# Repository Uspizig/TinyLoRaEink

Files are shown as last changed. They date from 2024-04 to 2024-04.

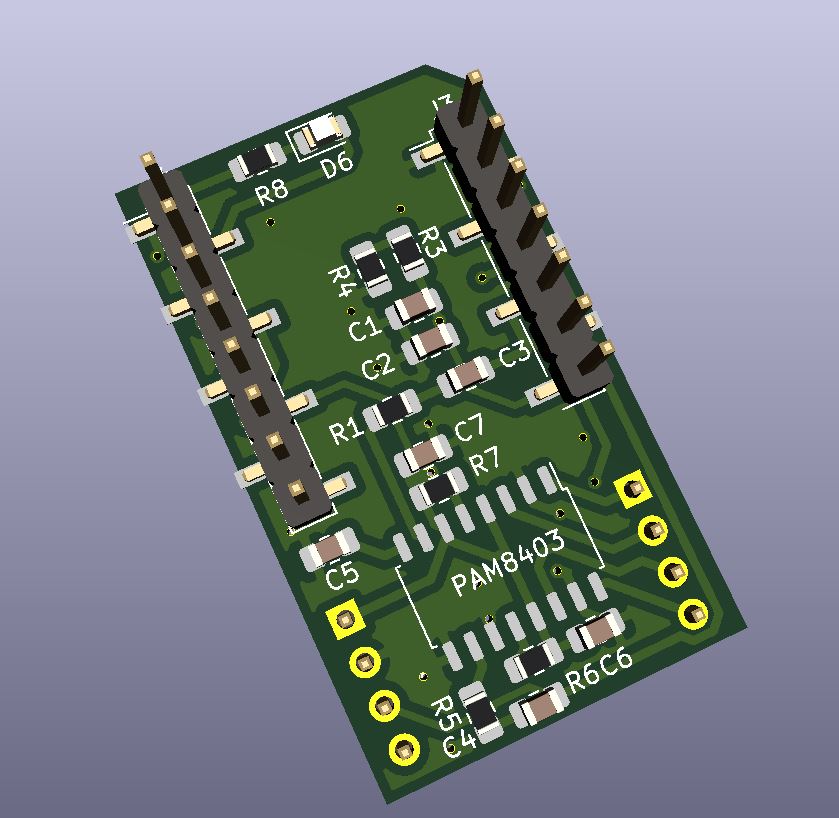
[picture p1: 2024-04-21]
1.JPG

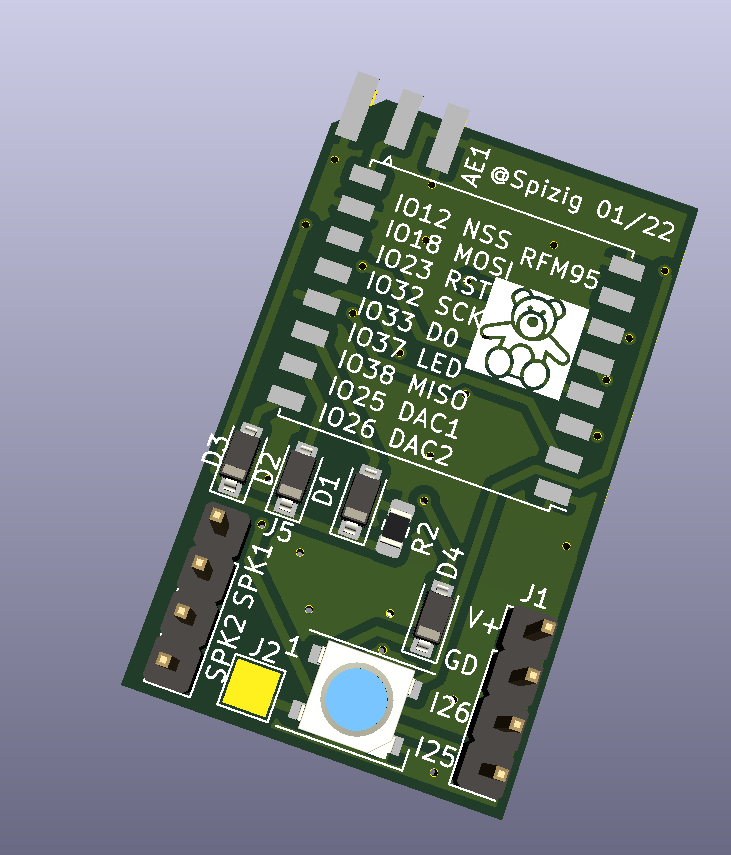
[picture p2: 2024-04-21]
front.PNG

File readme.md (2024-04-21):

This is a Lora Shield for the Lilygo Mini Epaper Core 1.05". 
With this shield you may enable LoRa Communication, Chirpstack or stupid Helium on a Lilygo Mini Epaper Core ESP32 (Not the S3 for now)

In the Attached folder you may find

Schematic(PDF)
Gerber Files(Zip File)
Demofiles for reading out a Bresser Weather Station
Changes in the SW for https://github.com/mcci-catena/arduino-lmic
You may change the following lines in the SW of Arduino-LMIC: To do this Change in the folder Arduino\libraries\arduino-lmic-master\src\hal the File hal.cpp the function "static void hal_spi_init to": static void hal_spi_init () { //SPI.begin();//Comment Uspizig Original und WEMOS D1 //SPI.begin(lmic_pins.sck, lmic_pins.miso, lmic_pins.mosi, lmic_pins_cs); //sck, miso, mosi, cs SPI.begin(23, 22, 19, 33);//Comment Uspizig M5Matrix Lora Modul }

Part List/BOM: SMD-Stiftleiste: SMD RM2.54 z.B. https://www.conrad.de/de/p/fischer-elektronik-stiftleiste-standard-anzahl-reihen-1-polzahl-je-reihe-20-sl-10-smd-062-20-z-1-st-739077.html

MBR0530-SOD123: D1, D2, D3 -> Anode towards RFM95 DIO0, DIO1, DIO2 Kathode direction to D4, R1 https://www.conrad.de/de/p/mbr-0530-t1g-diode-schottky-smd-0-5a-30v-sod123-inhalt-50-stueck-800112525.html

0805 Resistor 4k7 or 10k or 1k PullDown Resistor-> R2 Choose whatever you have availible in Kohm.

RFM95 Lora TTN Module: https://www.conrad.de/de/p/rfm95w-868-s2-lora-module-868mhz-20-123dbm-300kbps-1-8-3-7v-800167586.html

Wire as a Antenna L = 3 x 10^8 m/s : 868 MHz : 4 = 86,3 mm

Optional: C1 100nF 0805 C2 1µF 0805

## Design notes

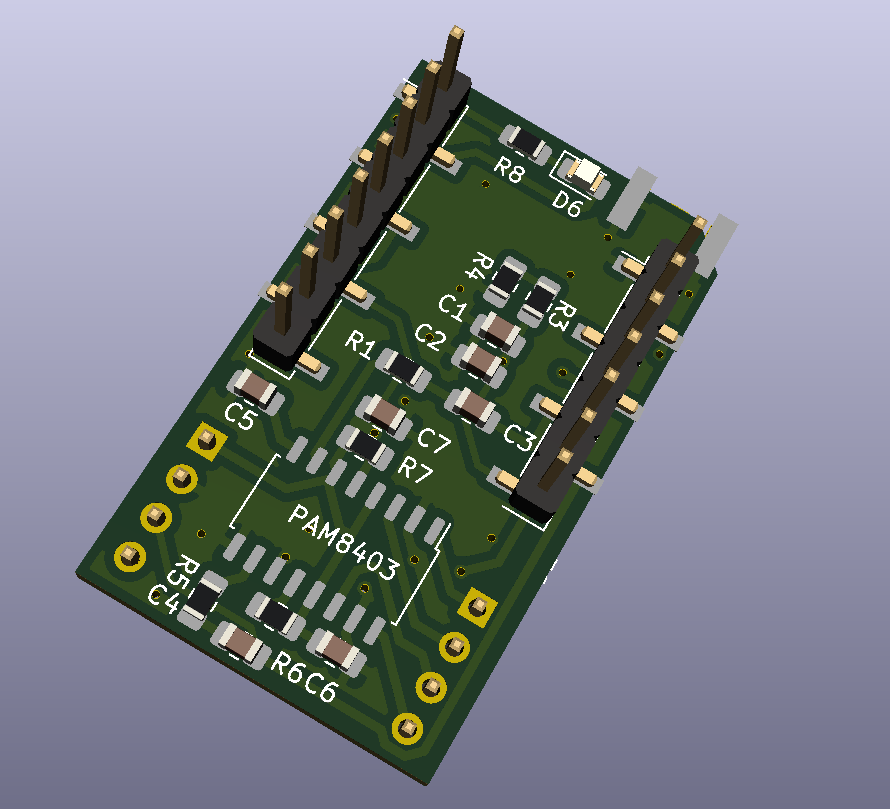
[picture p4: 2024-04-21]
back.PNG

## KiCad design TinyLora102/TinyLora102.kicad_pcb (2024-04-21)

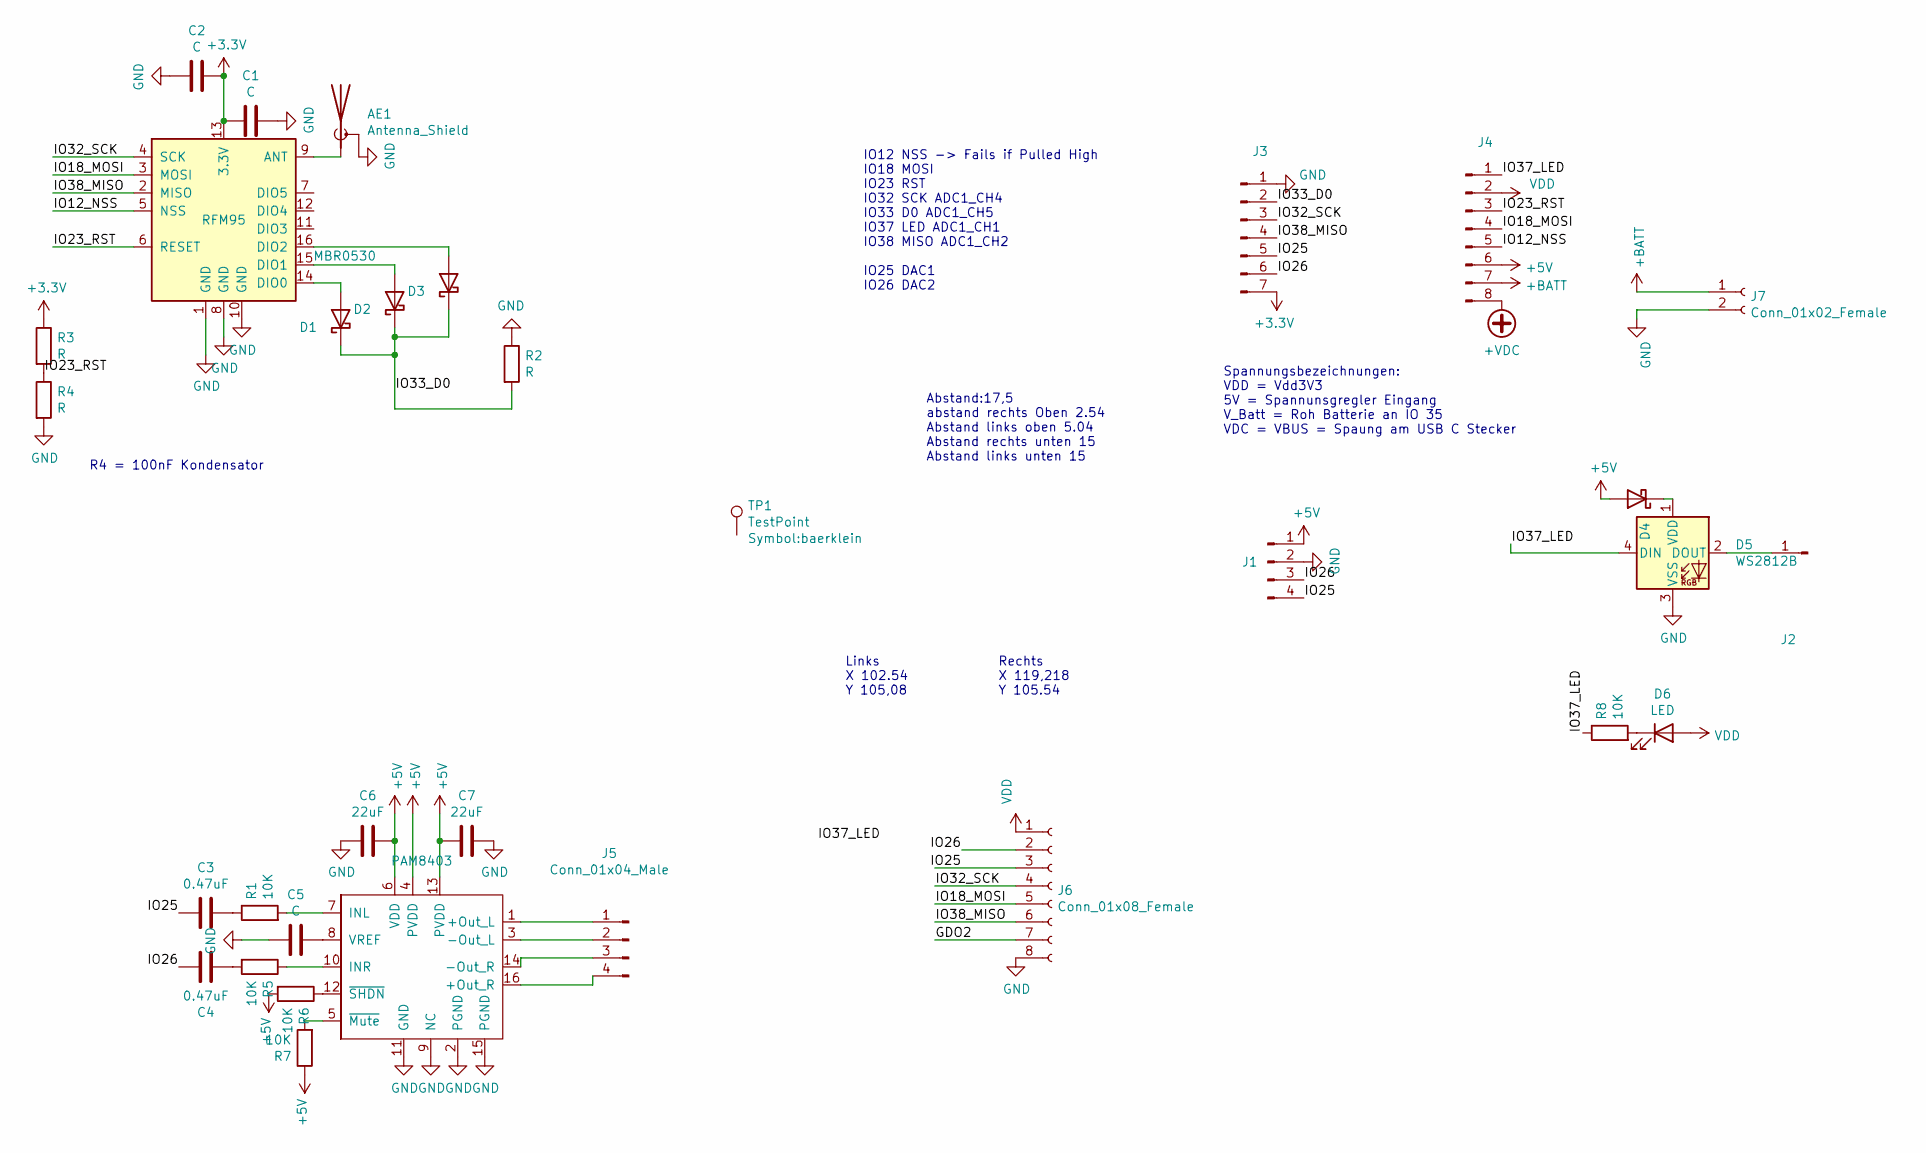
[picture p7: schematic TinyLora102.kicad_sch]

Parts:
AE1: Antenna_Shield; SMA_Samtec_SMA-J-P-H-ST-EM1_EdgeMount
C1, C2, C5: C; C_0805_2012Metric_Pad1.15x1.40mm_HandSolder
C3, C4: 0.47uF; C_0805_2012Metric_Pad1.15x1.40mm_HandSolder
C6, C7: 22uF; C_0805_2012Metric_Pad1.15x1.40mm_HandSolder
D1, D2, D3, D4: MBR0530; D_SOD-123
D5: WS2812B; LED_WS2812B_PLCC4_5.0x5.0mm_P3.2mm
D6: LED; LED_0805_2012Metric_Pad1.15x1.40mm_HandSolder
J1, J5: Conn_01x04_Male; PinHeader_1x04_P2.54mm_Vertical
J2: Conn_01x01_Male; TestPoint_Pad_2.5x2.5mm
J3: Conn_01x07_Male; PinHeader_1x07_P2.54mm_Vertical_SMD_Pin1Left
J4: Conn_01x08_Male; PinHeader_1x08_P2.54mm_Vertical_SMD_Pin1Left
J6: Conn_01x08_Female; PinHeader_1x08_P1.27mm_Vertical
J7: Conn_01x02_Female; JST_GH_SM02B-GHS-TB_1x02-1MP_P1.25mm_Horizontal
PAM8403: PAM8403; SOP-16_4.55x10.3mm_P1.27mm
R1, R5, R6, R7, R8: 10K; R_0805_2012Metric_Pad1.15x1.40mm_HandSolder
R2, R3, R4: R; R_0805_2012Metric_Pad1.15x1.40mm_HandSolder
RFM95: RFM95W-868S2; HOPERF_RFM9XW_SMD_3D
TP1: TestPoint; baerklein

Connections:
+3V3: C1.2, C2.1, J3.7, R3.1, RFM95.13 (3.3V)
+5V: C6.1, C7.2, D4.2 (A), J1.1, J4.6, PAM8403.4 (PVDD), PAM8403.6 (VDD), PAM8403.13 (PVDD), R6.2, R7.1
+BATT: J4.7, J7.1; also elsewhere on the board
+VDC: J4.8
/GDO2: J6.7
/IO12_NSS: J4.5, RFM95.5 (NSS)
/IO18_MOSI: J4.4, J6.5, RFM95.3 (MOSI)
/IO23_RST: J4.3, R3.2, R4.1, RFM95.6 (RESET)
/IO25: C3.2, J1.4, J3.5, J6.3
/IO26: C4.1, J1.3, J3.6, J6.2
/IO32_SCK: J3.3, J6.4, RFM95.4 (SCK)
/IO33_D0: D1.1 (K), D2.1 (K), D3.1 (K), J3.2, R2.2
/IO37_LED: D5.4 (DIN), J4.1, R8.1
/IO38_MISO: J3.4, J6.6, RFM95.2 (MISO)
GND: AE1.2 (Shield), C1.1, C2.2, C5.2, C6.2, C7.1, D5.3 (VSS), J1.2, J3.1, J6.8, J7.2, PAM8403.2 (PGND), PAM8403.9 (NC), PAM8403.11 (GND), PAM8403.15 (PGND), R2.1, R4.2, RFM95.1 (GND), RFM95.8 (GND), RFM95.10 (GND); also elsewhere on the board
unnamed: AE1.1 (A), RFM95.9 (ANT)
unnamed: C3.1, R1.1
unnamed: C4.2, R5.2
unnamed: C5.1, PAM8403.8 (VREF)
unnamed: D1.2 (A), RFM95.14 (DIO0)
unnamed: D2.2 (A), RFM95.15 (DIO1)
unnamed: D3.2 (A), RFM95.16 (DIO2)
unnamed: D4.1 (K), D5.1 (VDD)
unnamed: D5.2 (DOUT), J2.1
unnamed: D6.1 (K), R8.2
unnamed: J5.1, PAM8403.1 (+Out_L)
unnamed: J5.2, PAM8403.3 (-Out_L)
unnamed: J5.3, PAM8403.14 (-Out_R)
unnamed: J5.4, PAM8403.16 (+Out_R)
unnamed: PAM8403.5 (~Mute), R7.2
unnamed: PAM8403.7 (INL), R1.2
unnamed: PAM8403.10 (INR), R5.1
unnamed: PAM8403.12 (~SHDN), R6.1
VDD: D6.2 (A), J4.2, J6.1

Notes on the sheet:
Spannungsbezeichnungen: VDD = Vdd3V3 5V = Spannunsgregler Eingang V_Batt = Roh Batterie an IO 35 VDC = VBUS = Spaung am USB C Stecker
Abstand:17,5 abstand rechts Oben 2.54 Abstand links oben 5.04 Abstand rechts unten 15 Abstand links unten 15
Rechts X 119,218 Y 105.54
Links X 102.54 Y 105,08
IO12 NSS -> Fails if Pulled High IO18 MOSI IO23 RST IO32 SCK ADC1_CH4 IO33 D0 ADC1_CH5 IO37 LED ADC1_CH1 IO38 MISO ADC1_CH2 IO25 DAC1 IO26 DAC2
R4 = 100nF Kondensator

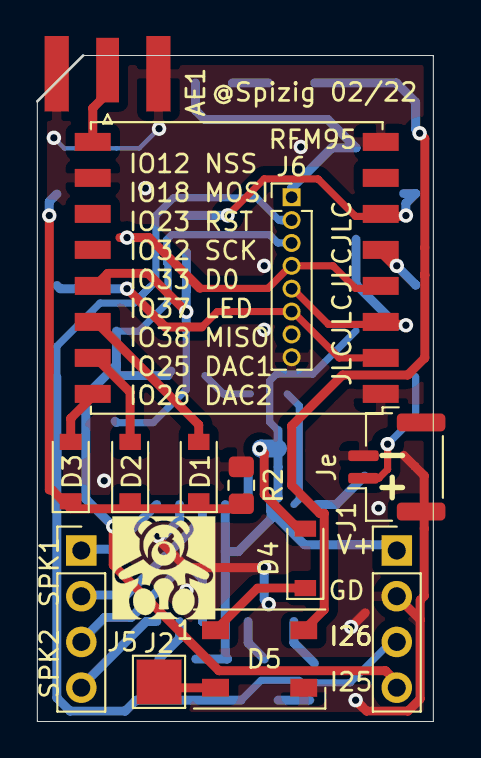
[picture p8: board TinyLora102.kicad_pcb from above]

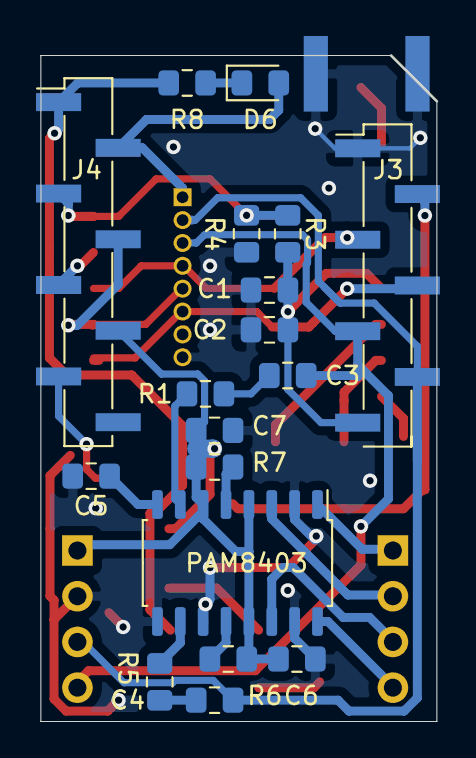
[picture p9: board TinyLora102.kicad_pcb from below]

Board: 2 copper layers, 22.0 x 37.0 mm, 32 parts (18 on the bottom side), 32 nets.

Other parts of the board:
Je: Conn_01x02_Female; JST_GH_SM02B-GHS-TB_1x02-1MP_P1.25mm_Horizontal

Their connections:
+BATT: Je.1; also elsewhere on the board
GND: Je.2; also elsewhere on the board

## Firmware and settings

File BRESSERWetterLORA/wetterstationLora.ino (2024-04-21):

//Features:
// - V3 Stack TTN Kompatibel, Ardunio ESP32 Core V2.0 Tested
// - Macht OTAA Join einmal im Leben, dann nur noch ABP
// - Decodiert 
// Geraet 9 = Self Made Hardware
// Geraet10 = TTGO LORA32 T3 V1.6

//To make this sketch work:

//Download these libs
/*
Libs: 
https://www.partsnotincluded.com/fastled-rgbw-neopixels-sk6812/
https://github.com/FastLED/FastLED
https://github.com/matthias-bs/BresserWeatherSensorReceiver
https://github.com/mcci-catena/arduino-lmic

*/

//MANDATORY CHANGES to MAKE IT WORK
//Hal.cpp changes:
//in hal.cpp replaced spi.begin(); to spi.begin(14, 2, 15, 26); to match YOUR pinning (lmic_pins.sck, lmic_pins.miso, lmic_pins.mosi, lmic_pins.nss)
  //SPI.begin();
/*
static void hal_spi_init () {
    //SPI.begin();//Original Änderung in hal.cpp
  //SPI.begin(lmic_pins.sck, lmic_pins.miso, lmic_pins.mosi, lmic_pins.nss);
  SPI.begin(14, 2, 15, 26);//this should match your pinning.. i copied a demo hal.cpp in the github folder
}

//Weathersensor.cpp
//Replace in the lib SRC folder https://github.com/matthias-bs/BresserWeatherSensorReceiver the weathersensor.cpp file with mine
// add in your folder the WaetherSensor.cfg file.
*/




//for Debugging
//#define SingleChannelMode 1 //to check on own gateway Join Behaviour
#define LMIC_DEBUG_LEVEL 1

#define geraet11 //TTGO MINI EPAPER CORE 1.02" // WETTER 02 in Wildwetter

//const unsigned long UpdateInterval = (60L * 20L - 03) * 1000000L; // Update delay in microseconds
//#define uS_TO_S_FACTOR 1000000  /* Conversion factor for micro seconds to seconds */


//Battery Pin
#define BATTERY_PIN 35
#include "OTA.h"
#include "credentials.h" 

#include "lorapindef_and_features.h"  
#include <lmic.h>
#include <hal/hal.h>
#include <SPI.h>
#include <EEPROM.h>

#include <FastLED.h> //https://github.com/FastLED/FastLED
#include <LoraMessage.h> //https://github.com/thesolarnomad/lora-serialization/

// include the library
#ifdef CC1101_CONNECTED
  #include <RadioLib.h>
  // https://github.com/jgromes/RadioLib
  SPIClass spiCC1101(VSPI);//https://github.com/espressif/arduino-esp32/issues/1219
  CC1101 radio = new Module(CC_CS, CC_GD0, RADIOLIB_NC, CC_GD2, spiCC1101, SPISettings()); //https://github.com/jgromes/RadioLib/issues/168
  //CC1101 radio = new Module(CC_CS, CC_GD0, RADIOLIB_NC, CC_GD2);
  byte fullMessage[40];
  bool receivedFlag = false;
  bool enableInterrupt = true;
  
#endif

#ifdef RFM95_WEATHER_DECODER
    #include "WeatherSensorCfg.h"
    #include "WeatherSensor.h" //https://github.com/matthias-bs/BresserWeatherSensorReceiver
    WeatherSensor weatherSensor;
#endif


#ifdef SSD1306_DISPLAY
  #include <Adafruit_GFX.h>
  #include <Adafruit_SSD1306.h>
  #define SCREEN_WIDTH 128 // OLED display width, in pixels
  #define SCREEN_HEIGHT 64 // OLED display height, in pixels
  #define OLED_SDA 21
  #define OLED_SCL 22 
  Adafruit_SSD1306 display(SCREEN_WIDTH, SCREEN_HEIGHT, &Wire);
#endif

#ifdef EINKDISPLAY102TTGO
  #include <GxEPD2_BW.h>
  #include <GxEPD2_3C.h>
  #include <Fonts/FreeMonoBold9pt7b.h>

  #include <GxEPD2_BW.h>
  #include "GxEPD2_boards_added.h"
  GxEPD2_BW<GxEPD2_102, GxEPD2_102::HEIGHT> display(GxEPD2_102(/*CS=5*/ E_INK_PIN_SPI_CS, /*DC=*/ E_INK_PIN_SPI_DC, /*RST=*/ E_INK_PIN_SPI_RST, /*BUSY=*/ E_INK_PIN_SPI_BUSY)); // GxEPD2_102
  #define Large  5           // For icon drawing, needs to be odd number for best effect
  #define Small  3            // For icon drawing, needs to be odd number for best effect
  boolean LargeIcon = true, SmallIcon = false; //250x122 Pixel
  const uint16_t window_x = 0;
  const uint16_t window_y = 0;
  const uint16_t window_width = 128;
  const uint16_t window_height = 80;
#endif
//Led Einstellungen
  
  FASTLED_USING_NAMESPACE
  #define MAX_POWER_MILLIAMPS 500
  #ifdef WS2812_LEDS
    CRGB leds[ANZAHL_LEDS];
    CRGB leds2[OBEN_LEDS];
  #endif
  #ifdef SK6812_LEDS
    #include "FastLED_RGBW.h" //https://www.partsnotincluded.com/fastled-rgbw-neopixels-sk6812/
    CRGBW leds[ANZAHL_LEDS];
    CRGB *ledsRGB = (CRGB *) &leds[0];

    //Beleuchtung des Drehreglers
    CRGBW leds2[OBEN_LEDS];
    CRGB *ledsRGB2 = (CRGB *) &leds2[0];
  #endif  
  static uint8_t gHue = 0;

uint8_t hue, hue2 = 0;
boolean zielwert_erreicht =0;
uint8_t Aktuelle_LED=0;
uint8_t schleifenzaehler = 0;
int vorher_message =0;
int counter = 0;
int lastcounter=0;
int counter_last=0;
int setup_lora_sucesful_flag =0;



//Temperatur:
#include <Wire.h>
#ifdef BMP280_CONNECTED
  #include <Adafruit_BMP280.h>
  Adafruit_BMP280 bmp; // I2C
#endif

#ifdef BME280_CONNECTED
  #define SEALEVELPRESSURE_HPA (1013.25)
  #include <Adafruit_BME280.h>
  Adafruit_BME280 bme;
#endif

#ifdef CCS811_CONNECTED 
  #include <SparkFunCCS811.h> //Click here to get the library: http://librarymanager/All#SparkFun_CCS811
  CCS811 myCCS811(CCS811_ADRESS);
#endif



#ifdef geraet3
  #define sda 21 ///* I2C Pin Definition */
  #define scl 22 ///* I2C Pin Definition */
#else
  #define sda 21 ///* I2C Pin Definition */
  #define scl 22 ///* I2C Pin Definition */
#endif


#ifdef WIFISCAN_CONNECTED
  long lastMsg = 0;
  #define updaterateWIFI 3000
#endif


#ifdef CC1101_CONNECTED
  float temp_cc1101 =0;
  float humidity_cc1101 =0;
  int pressure_cc1101 =0;
  int rain_cc1101 =0;
  int wind_speed_cc1101 =0;
  int wind_speed_max_cc1101 =0;
  int wind_dir_cc1101 =0;
  int count_decoded_wind_messages =0;
#endif

#ifdef RFM95_WEATHER_DECODER
  float temp_cc1101 =0;
  float humidity_cc1101 =0;
  int pressure_cc1101 =0;
  int rain_cc1101 =0;
  int wind_speed_cc1101 =0;
  int wind_speed_max_cc1101 =0;
  int wind_dir_cc1101 =0;
  int count_decoded_wind_messages =0;
#endif

float temp = 23;
float pressure = 980;
float humidity = 50;
float ccs811_CO2 = 450;
float ccs811_TVOC = 2;
int battery = 50;
int port = 1;

typedef struct {
   int Temp;
   int Feuchte;
   int Temp_max;
   int Temp_min;
   int Condition_Code;
   int Muell_Code;
} payload_record_type;
  
payload_record_type vorhersage[1];





#include "esp_timer.h"
#include "Arduino.h"
#include "fb_gfx.h"
//#include "fd_forward.h"
//#include "fr_forward.h"
#include "soc/soc.h"           // Disable brownout problems
#include "soc/rtc_cntl_reg.h"  // Disable brownout problems
#include "driver/rtc_io.h"
#include "WiFi.h"
#include <WiFiClientSecure.h>
#include <ArduinoJson.h> 
#include "credentials.h"  
//char ssid[] = mySSID;     // your network SSID (name)
//char password[] = myPASSWORD; // your network key


WiFiClientSecure client;

/*Wifi Sort Test*/
#define WIFI_DELAY        500
#define MAX_SSID_LEN      32 /* Max SSID octets. */
char ssid2[MAX_SSID_LEN] = "";/* SSID that to be stored to connect. */
#define WIFI_DELAY        500/* Delay paramter for connection. */

typedef struct { /*Struct für einfache Speicherung der Daten*/
  
   byte mac0;
   byte mac1;
   byte mac2;
   byte mac3;
   byte mac4;
   byte mac5;
   String mac;
   int EmpfangsPegel;
   int Encrypted;
} Wifi_record_type;
Wifi_record_type Found_Wifi[5];




uint32_t start_time;
uint32_t next_time;
uint32_t previous_time;
uint32_t previous_full_update;

uint32_t total_seconds = 0;
uint32_t startup_seconds = 0;
uint32_t seconds, minutes, hours, days;

uint32_t join_total_seconds = 0;
uint32_t join_seconds, join_minutes, join_hours, join_days;

//Partial Update:
const uint32_t partial_update_period_s = 30;
//const uint32_t full_update_period_s = 60 * 60 * 60;//alle 2.5 Tage
const uint32_t full_update_period_s = 60 * 60;//(jede Stunde)
//const uint32_t full_update_period_s = 60;(jede Minute)
/*EINK Teile ENDE*/

//Variables for ABP after OTAA Join
u1_t NWKSKEY[16] ;                               // LoRaWAN NwkSKey, network session key.
u1_t APPSKEY[16] ;                               // LoRaWAN AppSKey, application session key.
u4_t DEVADDR ;



//RealTimeVariables which don't get erased during Sleep
  struct Daten_struct {//https://esp32.com/viewtopic.php?t=11984
    uint16_t Stack[15];
    uint8_t Counter_History;
  };
  RTC_DATA_ATTR uint32_t SAVED_dataValid ;                           // DATAVALID if valid data (joined)
  RTC_DATA_ATTR uint8_t  SAVED_devaddr[4] ;                          // Device address after join
  RTC_DATA_ATTR uint8_t  SAVED_nwkKey[16] ;                          // Network session key after join
  RTC_DATA_ATTR uint8_t  SAVED_artKey[16] ;                          // Aplication session key after join
  RTC_DATA_ATTR uint32_t SAVED_seqnoUp ;                             // Sequence number       
  bool OTAA = true ;   //startup with OTAA if No EEPROM was Saved before
  //History of Data
  RTC_DATA_ATTR  struct Daten_struct Druck_Werte;                 
  RTC_DATA_ATTR  struct Daten_struct Temp_Werte;
  RTC_DATA_ATTR  struct Daten_struct CO2_Werte;
  RTC_DATA_ATTR  struct Daten_struct TVOC_Werte;                                                   
  RTC_DATA_ATTR  struct Daten_struct Feuchte_Werte;


// Boot Counter
RTC_DATA_ATTR uint32_t SAVED_boot_counter =0;

//variables for OTAA JOIN
  static const u1_t PROGMEM APPEUI[8]={ APP_EUI_LORA };//lsb
  void os_getArtEui (u1_t* buf) { memcpy_P(buf, APPEUI, 8);}
  
  static const u1_t PROGMEM DEVEUI[8]={ DEV_EUI_LORA };//lsb
  void os_getDevEui (u1_t* buf) { memcpy_P(buf, DEVEUI, 8);}

  //msb
  static const u1_t PROGMEM APPKEY[16] = { APP_KEY_LORA };
  void os_getDevKey (u1_t* buf) {  memcpy_P(buf, APPKEY, 16);}  



int verbunden_indicator = 0;
int Packet_Transmission_ongoing = 0; // Display wird nur aktualisiert wenn ein Paket gesendet wird
int packet_counter =0;
int packet_counter_rx =0;
static osjob_t sendjob;
devaddr_t DeviceName = 0;

//CC1101 Interruped Routine
#ifdef CC1101_CONNECTED
  static void IRAM_ATTR setFlag(void) {
      // check if the interrupt is enabled
      if (!enableInterrupt) {
          return;
      }
  
      // we got a packet, set the flag
      receivedFlag = true;
  }
#endif


// Pin mapping
#ifdef geraet10
  const lmic_pinmap lmic_pins = {
      .nss = LORA_PIN_SPI_NSS,
      .rxtx = LMIC_UNUSED_PIN,
      .rst = LORA_PIN_SPI_RST,
      .dio = {LORA_PIN_SPI_DIO0, LORA_PIN_SPI_DIO1, LMIC_UNUSED_PIN}, 
      .rxtx_rx_active = 0,//kopiert von TTGO Board
      .rssi_cal = 10,//kopiert von TTGO Board
      //.spi_freq = 8000000, /* 8MHz */ //kopiert von TTGO Board
      .spi_freq = 4000000, //4 MHZ from GxEPD2 https://github.com/ZinggJM/GxEPD2/tree/master/extras/sw_spi
  };
  
#elif geraet9
  const lmic_pinmap lmic_pins = {
      .nss = LORA_PIN_SPI_NSS,
      .rxtx = LMIC_UNUSED_PIN,
      .rst = LORA_PIN_SPI_RST,
      .dio = {LORA_PIN_SPI_DIO0, LORA_PIN_SPI_DIO1, LMIC_UNUSED_PIN}, 
      .rxtx_rx_active = 0,//kopiert von TTGO Board
      .rssi_cal = 10,//kopiert von TTGO Board
      //.spi_freq = 8000000, /* 8MHz */ //kopiert von TTGO Board
      .spi_freq = 4000000, //4 MHZ from GxEPD2 https://github.com/ZinggJM/GxEPD2/tree/master/extras/sw_spi
  };

#else
const lmic_pinmap lmic_pins = {
    .nss = LORA_PIN_SPI_NSS,
    .rxtx = LMIC_UNUSED_PIN,
    .rst = LMIC_UNUSED_PIN,
    #ifdef geraet1
      .dio = {LORA_PIN_SPI_DIO0, LORA_PIN_SPI_DIO1, LMIC_UNUSED_PIN}, 
    #else
      .dio = {LORA_PIN_SPI_DIO1, LORA_PIN_SPI_DIO1, LMIC_UNUSED_PIN}, 
    #endif
    .rxtx_rx_active = 0,//kopiert von TTGO Board
    .rssi_cal = 10,//kopiert von TTGO Board
    //.spi_freq = 8000000, /* 8MHz */ //kopiert von TTGO Board
    .spi_freq = 4000000, //4 MHZ from GxEPD2 https://github.com/ZinggJM/GxEPD2/tree/master/extras/sw_spi
};
#endif


  


//Hilfsfunktion um Hex Vafriablen auszugeben
void printHex2(unsigned v) {
    v &= 0xff;
    if (v < 16)
        Serial.print('0');
    Serial.print(v, HEX);
}
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
void loop() {
    #ifdef OTAWIFI_ENABLED
      ArduinoOTA.handle();
    #endif  
    
    #ifdef CC1101_CONNECTED
       if(verbunden_indicator == LORA_TX_INIT && count_decoded_wind_messages < 3){  
        if (!receivedFlag) {
          return; /// Mach nix wenn nix rempfangen wurde
        }
        else{
          enableInterrupt = false;
          receivedFlag = false;
          tryReadAndDecode();
          radio.startReceive();
          enableInterrupt = true;
         }
       }
       else{
          if (count_decoded_wind_messages >= 3 && setup_lora_sucesful_flag == 0){
            enableInterrupt = false;
            digitalWrite(CC_CS, LOW); //CC1101 Abschalten
            Serial.println("Genug Wetter Nachrichten empfangen - Starte LoRa Sender");
            setup_lora(); 
          }
          else{//Fall verbunden indicator ist höher als 0??
            os_runloop_once();  
            Serial.println("BIN hier drin");   
          }
       }
    #endif
    #ifdef RFM95_WEATHER_DECODER
      if(verbunden_indicator == LORA_TX_INIT && count_decoded_wind_messages < 3){  
        bool decode_ok = weatherSensor.getMessage();
        if (!decode_ok) {
          return; /// Mach nix wenn nix rempfangen wurde
        }
        else{
          tryReadAndDecodeRFM95();
         }
       }
       else{
          if (count_decoded_wind_messages >= 3 && setup_lora_sucesful_flag == 0){
            #ifdef SSD1306_DISPLAY
              displayWeatherData();
            #endif  
            #ifdef EINKDISPLAY102TTGO
              displayWeatherData();
            #endif  
            Serial.println("Genug Wetter Nachrichten empfangen - Starte LoRa Sender");
            setup_lora(); 
          }
          else{//Fall verbunden indicator ist höher als 0??
            os_runloop_once();     
          }
       }
    #endif
    
    if (verbunden_indicator == LORA_TX_COMPLETED){
     kurzschlaf();
    }
   
}

//Temperaturmessungen

#ifdef BME280_CONNECTED
    int BME_Start(void){
      bool status;
        Wire.begin(sda, scl);
        status = bme.begin(BME_ADRESS);   
        Serial.print("BME check: "); Serial.print(status);
        if (!status) {
            Serial.println("No BME280 I2C sensor, check wiring!");
            return 0;
        }
        else{
          Serial.println("BME gefunden");
          return 1;
        }
    }
    
    void BME_Test(void){
         
          Serial.print("BME280 I2C: ");
          Serial.print("Temp = ");
          Serial.print(bme.readTemperature());
          Serial.print(" *C ");
      
          Serial.print("Druck = ");
          Serial.print(bme.readPressure() / 100.0F);
          Serial.print(" hPa ");
    
          Serial.print("Feuchte = ");
          Serial.print(bme.readHumidity());
          Serial.print(" % \n");
          
          temp = bme.readTemperature();
          pressure = bme.readPressure()/ 100.0F;
          humidity = bme.readHumidity();
          SAVE_DATA_2_RTC((int)temp, &Temp_Werte);
          SAVE_DATA_2_RTC((int)humidity, &Feuchte_Werte);
          //SAVE_DATA_2_RTC((int)(pressure-870.0), &Druck_Werte);//Alte Version mit Uint8_t 
          SAVE_DATA_2_RTC((int)(pressure), &Druck_Werte);
    }
#endif

#ifdef BMP280_CONNECTED
    int BMP_Start(void){
      bool status;
        Wire.begin(sda, scl);
        
          status = bmp.begin(BMP_ADRESS,0x58); //alternative BMP Adress
          //status = bmp.begin();  
        
        
        Serial.print("BMP check: "); Serial.print(status);
        if (!status) {
            Serial.println("No BMP280 I2C sensor, check wiring!");
            return 0;
        }
        else{
          Serial.println(" BMP280 gefunden");
          /* Default settings from datasheet. */
          bmp.setSampling(Adafruit_BMP280::MODE_NORMAL,     /* Operating Mode. */
                      Adafruit_BMP280::SAMPLING_X2,     /* Temp. oversampling */
                      Adafruit_BMP280::SAMPLING_X16,    /* Pressure oversampling */
                      Adafruit_BMP280::FILTER_X16,      /* Filtering. */
                      Adafruit_BMP280::STANDBY_MS_500); /* Standby time. */
          return 1;
        }
    }
    
    void BMP_Test(void){
                           
          temp = bmp.readTemperature();
          pressure = bmp.readPressure()/ 100.0F;
          //SAVE_DATA_2_RTC((int)temp, Temp_Werte);Serial.print("Temp:");Serial.println((int)temp);
          //SAVE_DATA_2_RTC((int)pressure, Druck_Werte);Serial.print("Druck:");Serial.println((int)pressure);
          SAVE_DATA_2_RTC((int)temp, &Temp_Werte);
          //SAVE_DATA_2_RTC((int)(pressure-870.0), &Druck_Werte); //870 = minimal jemals gemessener Druck-Alte Version
          SAVE_DATA_2_RTC((int)(pressure), &Druck_Werte);
    }
#endif 

#ifdef CCS811_CONNECTED
  void CCS811_Test(void){
      if (myCCS811.dataAvailable()){
          //Calling this function updates the global tVOC and eCO2 variables
          myCCS811.readAlgorithmResults();
          ccs811_CO2 = float(myCCS811.getCO2());
          ccs811_TVOC = float(myCCS811.getTVOC());
          
          Serial.print("CCS811 I2C: CO2 = "); Serial.print(ccs811_CO2); Serial.print(" ppm");
          Serial.print(" TVOC: "); Serial.print(ccs811_TVOC); Serial.println(" ppb");
          //Serial.print(myCCS811.getCO2());
          //Serial.print(myCCS811.getTVOC());
          
          #ifdef BME280_CONNECTED //for Calibration of Temp and humidity
            float BMEtempC = bme.readTemperature();
            float BMEhumid = bme.readHumidity();
            //Recalibration of CCS822 with BME280 Data
            myCCS811.setEnvironmentalData(BMEhumid, BMEtempC);
            Serial.print("Set CCS811 new values (deg C, %): ");
            Serial.print(BMEtempC); Serial.print(",");
            Serial.println(BMEhumid); Serial.println();
          #endif    
      }
  }
#endif

void kurzschlaf(void){
  //Serial.println("Schlafe in 5 sec...ztztztzt");
  SAVED_boot_counter++;
  delay(250);
  //esp_sleep_enable_ext0_wakeup(GPIO_NUM_13, 1);
  #define uS_TO_S_FACTOR 1000000 /* Conversion factor for micro seconds to seconds */ 
  esp_sleep_enable_timer_wakeup(TIME_TO_SLEEP * uS_TO_S_FACTOR);
  
  Serial.println("\n Going to sleep now");
  delay(500);
  esp_deep_sleep_start();
  delay(1000);
}
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

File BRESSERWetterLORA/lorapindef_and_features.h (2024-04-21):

#define LORA_TX_INIT 0
#define LORA_TX_JOINING 1
#define LORA_TX_JOINED 2
#define LORA_TX_STARTED 3
#define LORA_TX_COMPLETED 4



// Pinning

#ifdef geraet11 //TTGO Mini Epaper Core 1.02" inch screen // WETTER 02 in Wildwetter
//Check here your Version and Pinnings
  #define TTGOT5 1 //neded to indicate the E-INK Library a different pinning
  #define E_INK_PIN_SPI_BUSY 34
  #define E_INK_PIN_SPI_RST  4
  #define E_INK_PIN_SPI_DC   19
  #define E_INK_PIN_SPI_CS   5//13
  #define E_INK_PIN_SPI_DIN  21
  #define E_INK_PIN_SPI_SCK  22 
  #define E_INK_PIN_SPI_MISO -1//24//n/A

//Lora Pinning for ESP32 Base Board with Bresser Weather Station
  #define LORA_PIN_SPI_MOSI 18
  #define LORA_PIN_SPI_MISO 38
  #define LORA_PIN_SPI_SCK  32
  #define LORA_PIN_SPI_NSS  12  
  #define LORA_PIN_SPI_RST  23//27   
  #define LORA_PIN_SPI_DIO1 33
  #define LORA_PIN_SPI_DIO0 33

  #define SDCARD_CS               (13)
  #define SDCARD_MOSI             (15)
  #define SDCARD_MISO             (2)
  #define SDCARD_SCLK             (14)


//CC1101 Connections
  #define CC_MOSI 21
  #define CC_SCK 22
  #define CC_MISO 10
  #define CC_GD2 9
  #define CC_GD0 4
  #define CC_CS  2
  //LSB LSB MSB
  #define APP_EUI_LORA FILLMEIN
  #define DEV_EUI_LORA FILLMEIN
  #define APP_KEY_LORA FILLMEIN
#endif

//EEPROM HASH für Joins OTAA gegen die geprüft wird

// WETTER 02 in Wildwetter
#ifdef geraet11 
  #define DATAVALID 0xACF2AFC2                     // Pattern for data valid in EEPROM/RTC memory
#endif

// Features


#ifdef geraet11 //ESP32 TTGO LORA 32 V1.6
  #define TIME_TO_SLEEP  100        /* Time ESP32 will go to sleep (in seconds) */
  const unsigned TX_INTERVAL = 40; //180 TX Interval in Seconds
  //#define SSD1306_DISPLAY
  #define EINKDISPLAY102TTGO
  //#define CC1101_CONNECTED
  #define RFM95_WEATHER_DECODER
  #define WIFISCAN_CONNECTED
  //#define OTAWIFI_ENABLED
  //#define BME280_CONNECTED
  //#define BME_ADRESS 0x77
  //#define CCS811_CONNECTED
  //#define CCS811_ADRESS 0x5A
  #define ANZAHL_LEDS 1//36
  #define RGB_LED_DATA_PIN 0
  
  #define OBEN_LED_DATA_PIN 27
  #define OBEN_LEDS 1
  //#define SK6812_LEDS
  //#define WS2812_LEDS
  
#endif

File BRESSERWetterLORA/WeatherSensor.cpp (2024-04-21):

///////////////////////////////////////////////////////////////////////////////////////////////////
// WeatherSensor.cpp
//
// Bresser 5-in-1/6-in-1 868 MHz Weather Sensor Radio Receiver 
// based on CC1101 or SX1276/RFM95W and ESP32/ESP8266
//
// https://github.com/matthias-bs/WeatherSensor
//
// Based on:
// ---------
// Bresser5in1-CC1101 by Sean Siford (https://github.com/seaniefs/Bresser5in1-CC1101)
// RadioLib by Jan Gromeš (https://github.com/jgromes/RadioLib)
// rtl433 by Benjamin Larsson (https://github.com/merbanan/rtl_433) 
//     - https://github.com/merbanan/rtl_433/blob/master/src/devices/bresser_5in1.c
//     - https://github.com/merbanan/rtl_433/blob/master/src/devices/bresser_6in1.c
//
// created: 05/2022
//
//
// MIT License
//
// Copyright (c) 2022 Matthias Prinke
// 
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
// History:
//
// 20220523 Created from https://github.com/matthias-bs/Bresser5in1-CC1101
// 20220524 Moved code to class WeatherSensor
// 20220526 Implemented getData(), changed debug output to macros,
//          changed radio transceiver instance to member variable of WeatherSensor
//          (with initialization of 'Module' from WeatherSensor's constructor parameters)
//
//
// ToDo: 
// -
//
///////////////////////////////////////////////////////////////////////////////////////////////////

#include "WeatherSensor.h"

#if defined(USE_CC1101)
    static CC1101 radio = new Module(PIN_RECEIVER_CS, PIN_RECEIVER_IRQ, RADIOLIB_NC, PIN_RECEIVER_GPIO);
#endif
#if defined(USE_SX1276)
//    static SX1276 radio = new Module(PIN_RECEIVER_CS, PIN_RECEIVER_IRQ, PIN_RECEIVER_RST, PIN_RECEIVER_GPIO);
SPIClass spiCC1101(HSPI);//https://github.com/espressif/arduino-esp32/issues/1219      
static SX1276 radio = new Module(PIN_RECEIVER_CS, PIN_RECEIVER_IRQ, PIN_RECEIVER_RST, PIN_RECEIVER_GPIO,  spiCC1101, SPISettings());
#endif

int16_t WeatherSensor::begin(void) {
    // https://github.com/RFD-FHEM/RFFHEM/issues/607#issuecomment-830818445
    // Freq: 868.300 MHz, Bandwidth: 203 KHz, rAmpl: 33 dB, sens: 8 dB, DataRate: 8207.32 Baud
    DEBUG_PRINT(RECEIVER_CHIP);
    DEBUG_PRINTLN(" Initializing ... ");
    // carrier frequency:                   868.3 MHz
    // bit rate:                            8.22 kbps
    // frequency deviation:                 57.136417 kHz
    // Rx bandwidth:                        270.0 kHz (CC1101) / 250 kHz (SX1276)
    // output power:                        10 dBm
    // preamble length:                     40 bits
    #ifdef USE_CC1101
        int state = radio.begin(868.3, 8.21, 57.136417, 270, 10, 32);
    #else
        spiCC1101.begin(CC_SCK, CC_MISO, CC_MOSI, PIN_RECEIVER_CS);
        int state = radio.beginFSK(868.3, 8.21, 57.136417, 250, 10, 32);
    #endif
    if (state == RADIOLIB_ERR_NONE) {
        DEBUG_PRINTLN("success!");
        state = radio.setCrcFiltering(false);
        if (state != RADIOLIB_ERR_NONE) {
            DEBUG_PRINT(RECEIVER_CHIP);
            DEBUG_PRINT(" Error disabling crc filtering: [");
            DEBUG_PRINT(state);
            DEBUG_PRINTLN("]");
            while (true)
                ;
        }
        state = radio.fixedPacketLengthMode(27);
        if (state != RADIOLIB_ERR_NONE) {
            DEBUG_PRINT(RECEIVER_CHIP);
            DEBUG_PRINT(" Error setting fixed packet length: [");
            DEBUG_PRINT(state);
            DEBUG_PRINTLN("]");
            while (true)
                ;
        }
        // Preamble: AA AA AA AA AA
        // Sync is: 2D D4 
        // Preamble 40 bits but the CC1101 doesn't allow us to set that
        // so we use a preamble of 32 bits and then use the sync as AA 2D
        // which then uses the last byte of the preamble - we recieve the last sync byte
        // as the 1st byte of the payload.
        #ifdef USE_CC1101
            state = radio.setSyncWord(0xAA, 0x2D, 0, false);
        #else
            uint8_t sync_word[] = {0xAA, 0x2D};
            state = radio.setSyncWord(sync_word, 2);
        #endif
        if (state != RADIOLIB_ERR_NONE) {
            DEBUG_PRINT(RECEIVER_CHIP);
            DEBUG_PRINT(" Error setting sync words: [");
            DEBUG_PRINT(state);
            DEBUG_PRINTLN("]");
            while (true)
                ;
        }
    } else {
        DEBUG_PRINT(RECEIVER_CHIP);
        DEBUG_PRINT(" Error initialising: [");
        DEBUG_PRINT(state);
        DEBUG_PRINTLN("]");
        while (true)
            ;
    }
    DEBUG_PRINT(RECEIVER_CHIP);
    DEBUG_PRINTLN(" Setup complete - awaiting incoming messages...");
    rssi = radio.getRSSI();
    
    return state;
}


bool WeatherSensor::getData(uint32_t timeout, bool complete, void (*func)())
{
    const uint32_t timestamp = millis();
    bool saved_temp_ok = false;
    bool saved_rain_ok = false;
    bool decode_status = false;
    
    // Reset status flag 
    data_ok = false;
    
    while ((millis() - timestamp) < timeout) { 
        decode_status = getMessage();
    
        // Callback function (see https://www.geeksforgeeks.org/callbacks-in-c/)
        if (func) {
            (*func)();
        }
        
        // BRESSER_6_IN_1 message contains either temperature OR rain data
        // Save what has already been sent
        if (decode_status) {
            if (!complete) {
                // Incomplete data data is sufficient
                return data_ok = true;
            }
            if (temp_ok) {
                saved_temp_ok = true;
            }
            if (rain_ok) {
                saved_rain_ok = true;
            }
            if (saved_temp_ok && saved_rain_ok) {
                // Data complete
                return data_ok = true;
            }
        } // if (decode_status)
    } //  while ((millis() - timestamp) < timeout)
    
    // Timeout
    return false;
}
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

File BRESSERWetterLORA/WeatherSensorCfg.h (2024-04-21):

// Select appropriate sensor message format
//#define BRESSER_5_IN_1
#define BRESSER_6_IN_1

// Select type of receiver module
// (RFM95W: USE_SX1276)
//#define USE_CC1101
#define USE_SX1276

#define _DEBUG_MODE_

// Arduino default SPI pins
//
// Board   SCK   MOSI  MISO
// ESP8266 D5    D7    D6
// ESP32   D18   D23   D19

#if defined(ESP32)
/*    
	//PICO D4 Board
    #define PIN_RECEIVER_CS   5
    #define PIN_RECEIVER_IRQ  27     // CC1101: GDO0 / RFM95W/SX127x: G0
    #define PIN_RECEIVER_GPIO 25     // CC1101: GDO2 / RFM95W/SX127x: G1
    #define PIN_RECEIVER_RST  14     // RFM95W/SX127x - GPIOxx / CC1101 - RADIOLIB_NC

    #define CC_MOSI 23
    #define CC_SCK 18
    #define CC_MISO 19
*/   

 // LilyGo TTGO LORA32 V2.1.6
/*
    #define PIN_RECEIVER_CS   18
    #define PIN_RECEIVER_IRQ  26 // CC1101: GDO0 / RFM95W/SX127x: G0
    #define PIN_RECEIVER_GPIO 12 // CC1101: GDO2 / RFM95W/SX127x: G1
    #define PIN_RECEIVER_RST  23 // RFM95W/SX127x - GPIOxx / CC1101 - RADIOLIB_NC

    #define CC_MOSI 27
    #define CC_SCK 5
    #define CC_MISO 19
*/
// TTGO MINI E-Paper Core 1.02 " EINK Display

/*

    #define PIN_RECEIVER_CS   12
    #define PIN_RECEIVER_IRQ  33 // CC1101: GDO0 / RFM95W/SX127x: G0
    #define PIN_RECEIVER_GPIO -1//12 // CC1101: GDO2 / RFM95W/SX127x: G1//
    #define PIN_RECEIVER_RST  23 // RFM95W/SX127x - GPIOxx / CC1101 - RADIOLIB_NC

    #define CC_MOSI 18
    #define CC_SCK 32
    #define CC_MISO 38



*/
//M5Stack Atom Matrix mit Lora Aufsteck Board
/*
    #define PIN_RECEIVER_CS   33
    #define PIN_RECEIVER_IRQ  21 // CC1101: GDO0 / RFM95W/SX127x: G0
    #define PIN_RECEIVER_GPIO 21//12 // CC1101: GDO2 / RFM95W/SX127x: G1//
    #define PIN_RECEIVER_RST  25 // RFM95W/SX127x - GPIOxx / CC1101 - RADIOLIB_NC

    #define CC_MOSI 19
    #define CC_SCK 23
    #define CC_MISO 22
*/
//M5Stack Atom S3 mit Lora Aufsteck Board
    #define PIN_RECEIVER_CS   8
    #define PIN_RECEIVER_IRQ  39 // CC1101: GDO0 / RFM95W/SX127x: G0
    #define PIN_RECEIVER_GPIO -1//12 // CC1101: GDO2 / RFM95W/SX127x: G1//
    #define PIN_RECEIVER_RST  38 // RFM95W/SX127x - GPIOxx / CC1101 - RADIOLIB_NC

    #define CC_MOSI 6
    #define CC_SCK 7
    #define CC_MISO 5


    
#elif defined(ESP8266)
    #define PIN_RECEIVER_CS   15
    
    // CC1101: GDO0 / RFM95W/SX127x: G0
    #define PIN_RECEIVER_IRQ  4 
    
    // CC1101: GDO2 / RFM95W/SX127x: 
    #define PIN_RECEIVER_GPIO 5 
    
    // RFM95W/SX127x - GPIOxx / CC1101 - RADIOLIB_NC
    #define PIN_RECEIVER_RST  2
#endif
